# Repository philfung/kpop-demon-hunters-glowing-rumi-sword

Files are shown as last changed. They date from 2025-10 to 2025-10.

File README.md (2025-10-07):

# 🗡️ Rumi's Glowing Sword Prop (KPop Demon Hunters)

This guide provides instructions for creating a lightweight, glowing battery-powered replica of Rumi's sword, scaled for a 5-6 year old to hold comfortably. The sword is designed with a hollow interior to house the LED lighting and internal supports.





WARN: its a bit of work to do this DIY. if you don't enjoy this type of work, they may sell similar items on Etsy.

# ⚙️🔩📄 Bill of Materials

| Item Name | Purpose | Purchase Link |
| :--- | :--- | :--- |
| **3D Print Filament (Translucent Blue/Purple)** | Blade material, allows light pass-through. | https://www.amazon.com/iSANMATE-Filament-Transparent-Printing-Dimensional/dp/B0D4HR3PGB|
| **3D Print Filament (Gold Metal)** | Handle material. | [https://www.amazon.com/dp/B07RBSGZBM](https://www.amazon.com/dp/B07RBSGZBM) |
| **Battery-Powered Thin LED Light Strip** | Internal lighting for the glowing effect. | [https://www.amazon.com/dp/B0C4P9F9Y1](https://www.amazon.com/dp/B0C4P9F9Y1) |
| **Blade Support Rods** | Support the hollow blade| [https://www.amazon.com/dp/B0CN79NZ7Y](https://www.amazon.com/dp/B0CN79NZ7Y) |
| **Handle Support Rod** | Support the handle | https://www.amazon.com/FOCMKEAS-Carbon-6mm-400mm-Airplane/dp/B0DGF28DT8 |
| **Super Glue** | Bond all printed parts, LED strip, and support rods. | [https://www.amazon.com/dp/B0B1H2XD5S](https://www.amazon.com/dp/B0B1H2XD5S) |
| **Clear Tape** | tape LED strip to sword (optional, can use super glue) | https://www.amazon.com/Scotch-Dispenser-Narrow-Engineered-119/dp/B00006IF5G |

*Required tools* 
1. 3D printer
2. needle-nose pliers to remove supports.

---

# 🛠️ Assembly Instructions

1.  **Print Components:** 3D print [all files](3dfiles), using **translucent blue/purple** for parts prefixed with "blue" and **gold metal** for parts prefixed with "gold".
  


2.  **Reinforce Handle:**
   
  A. Glue [handle_1](3dfiles/gold_handle_1.stl) to [handle_2](3dfiles/gold_handle_2.stl)
  
  B. Place the Handle Support Rod through the hole of pieces [handle_2](3dfiles/gold_handle_2.stl), [handle_3](3dfiles/blue_handle_3.stl), [handle_4](3dfiles/gold_handle_4.stl), [handle_5](3dfiles/blue_handle_5.stl), [handle_6](3dfiles/gold_handle_6.stl), [handle_7](3dfiles/gold_handle_7.stl).  Glue pieces [handle_2](3dfiles/gold_handle_2.stl), [handle_3](3dfiles/blue_handle_3.stl), [handle_4](3dfiles/gold_handle_4.stl), [handle_5](3dfiles/blue_handle_5.stl), [handle_6](3dfiles/gold_handle_6.stl), [handle_7](3dfiles/gold_handle_7.stl). together, as well as each piece to the rod.



4.  **Prepare bottom half of the blade**:

  A. Glue [blue_blade_1_bottom](3dfiles/blue_blade_1_bottom.stl), [blue_blade_2_bottom](3dfiles/blue_blade_2_bottom.stl), [blue_blade_3_bottom](3dfiles/blue_blade_3_bottom.stl) together.
  
  B. Insert **two steel support rods** into the hollow interior (one on each side of the center channel) and glue them securely to the plastic walls.



5.  **Attach Handle to Blade:** **Glue** handle to blade, including the handle support rod.



5.  **Route LED Wire:** Pass the **LED strip's power cable** (the end nearest the battery pack/switch) through the dedicated small hole in [blade_1_top](3dfiles/blue_blade_1_top.stl).



6.  **Install Lighting:** Place the **LED strip** along the internal channel of the blade. Secure the strip with **tape and super glue** to prevent shifting and ensure light distribution.  



7.  **Final Closure:** Glue the second half of the blade, i.e [blade_1_top](3dfiles/blue_blade_1_top.stl), [blade_2_top](3dfiles/blue_blade_2_top.stl), [blade_3_top](3dfiles/blue_blade_3_top.stl), together and to the sword to finish the prop.



---

# 🙏 Acknowledgements

The 3d files are modified versions of the [Rumi Sword files from RavenCosplay](https://www.thingiverse.com/thing:7094317), edited to be scaled for a small child and hollowed out for internal electronics and support rods.

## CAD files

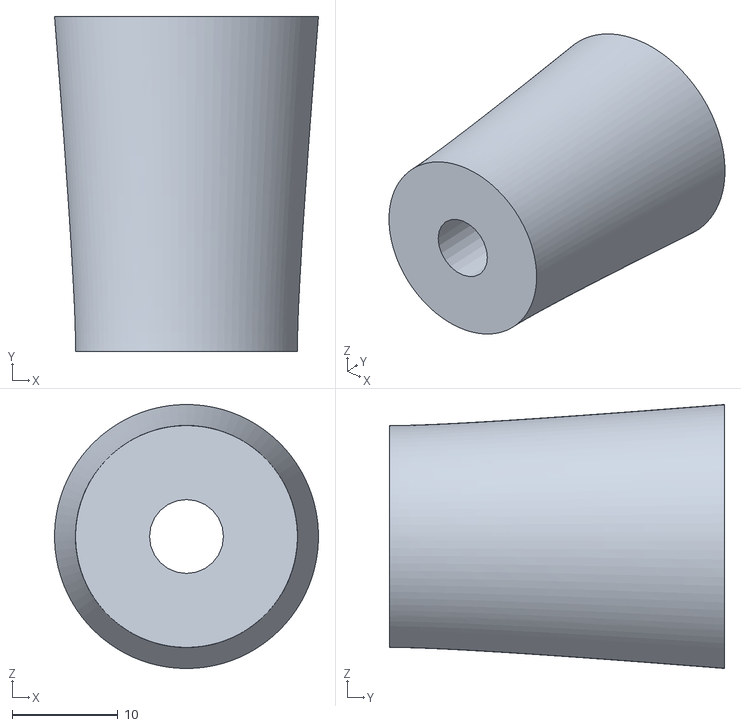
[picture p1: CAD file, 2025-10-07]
3dfiles/blue_handle_3.stl
25.0 x 31.8 x 25.0

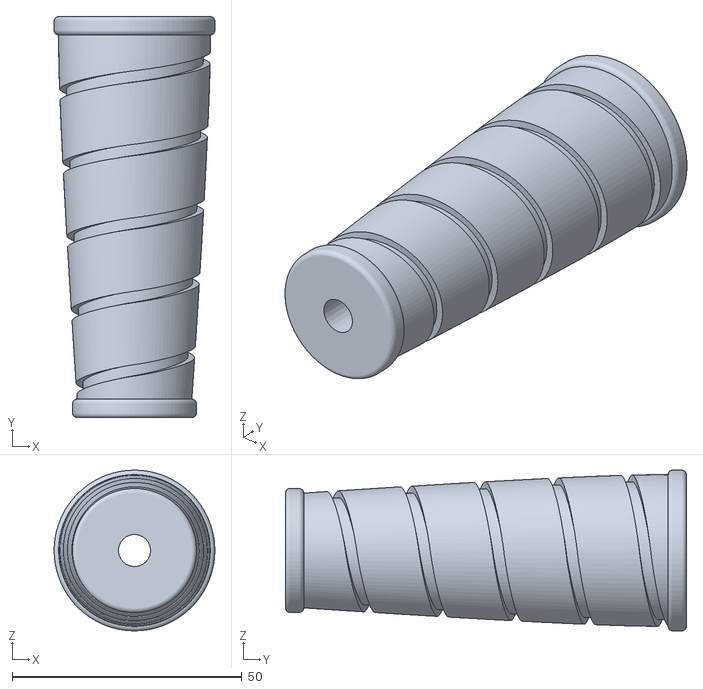
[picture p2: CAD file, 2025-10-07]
3dfiles/gold_handle_4.stl
35.0 x 87.3 x 35.0

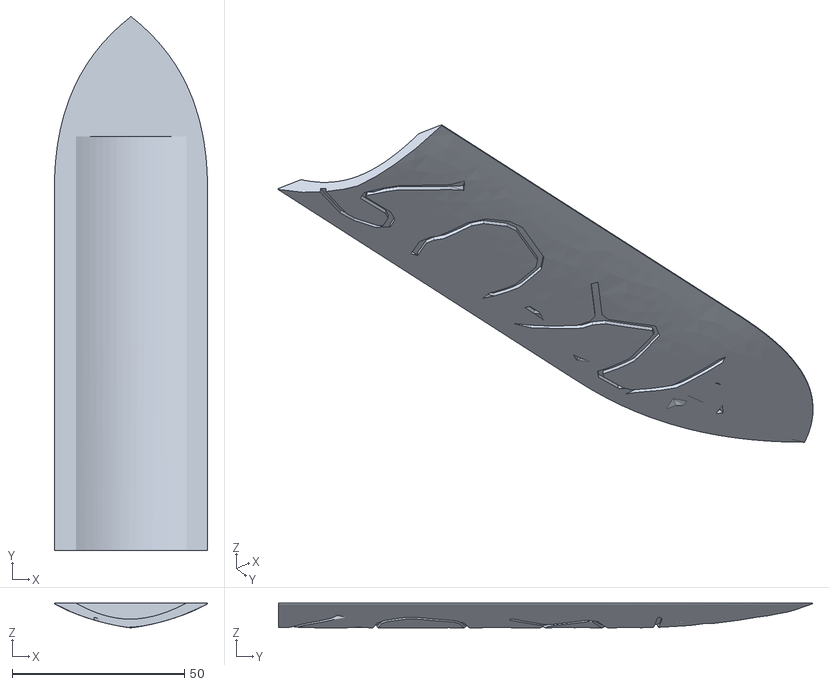
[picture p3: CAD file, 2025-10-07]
3dfiles/blue_blade_3_top.stl
44.5 x 154.9 x 7.21

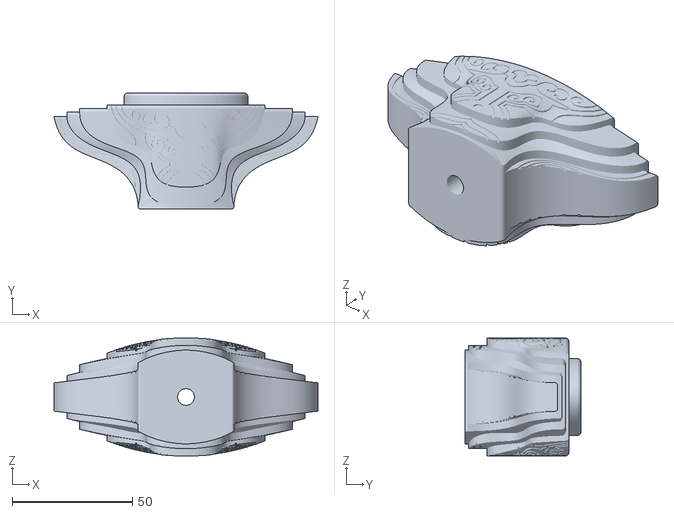
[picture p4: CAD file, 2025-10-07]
3dfiles/gold_handle_7.stl
109.8 x 48.2 x 49.0

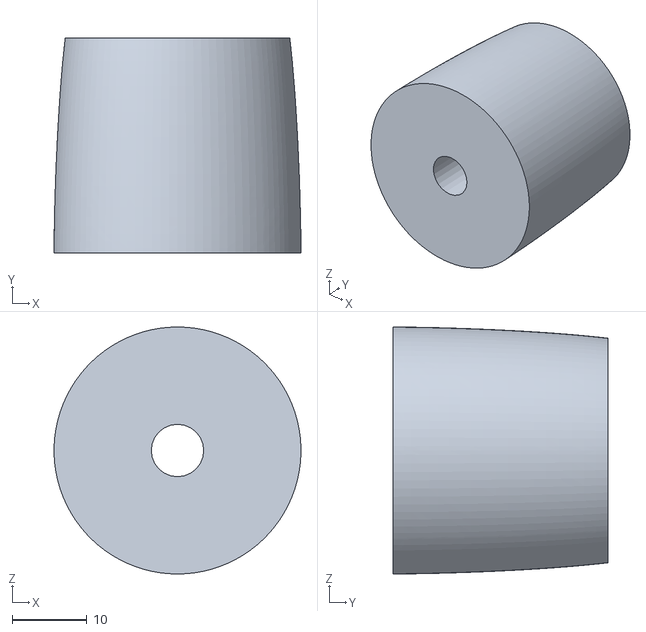
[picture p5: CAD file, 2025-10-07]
3dfiles/blue_handle_5.stl
33.0 x 28.8 x 33.0

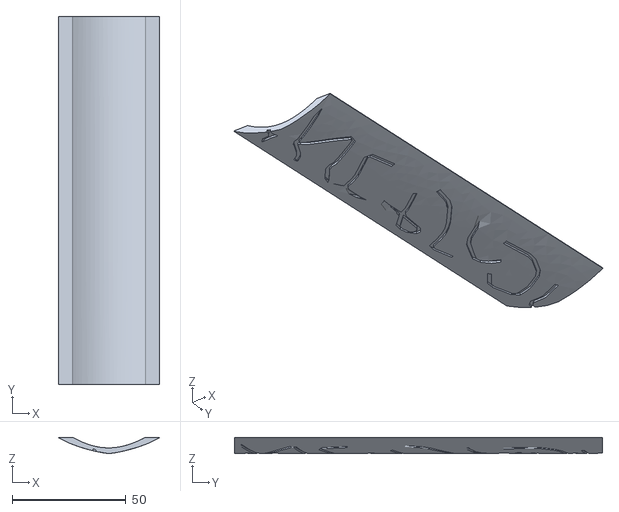
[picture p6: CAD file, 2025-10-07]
3dfiles/blue_blade_2_top.stl
44.5 x 161.6 x 7.21

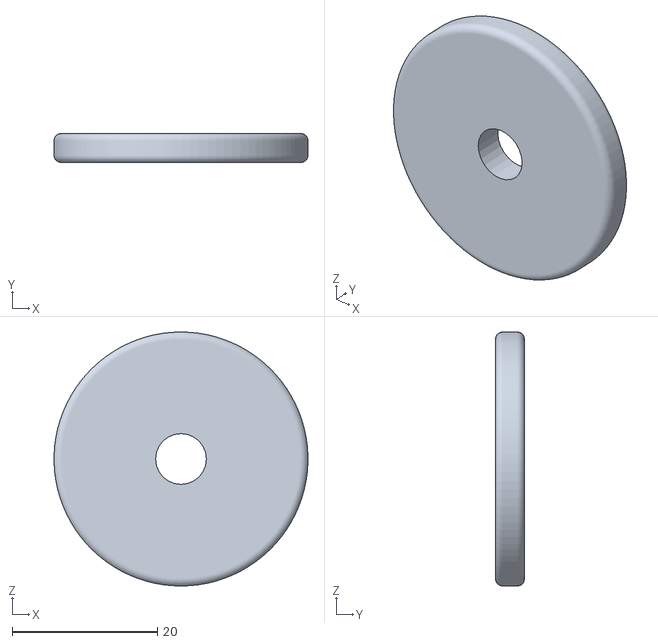
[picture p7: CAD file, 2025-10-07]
3dfiles/gold_handle_6.stl
35.0 x 4.00 x 35.0

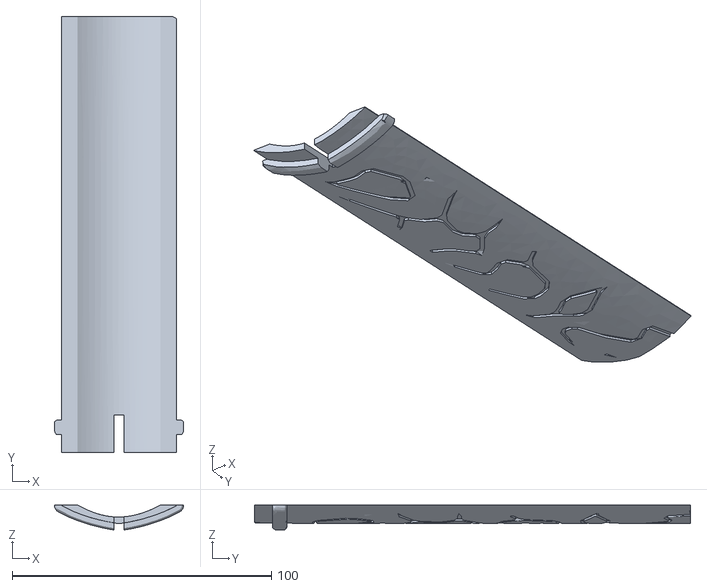
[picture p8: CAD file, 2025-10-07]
3dfiles/blue_blade_1_top.stl
49.9 x 168.2 x 9.64

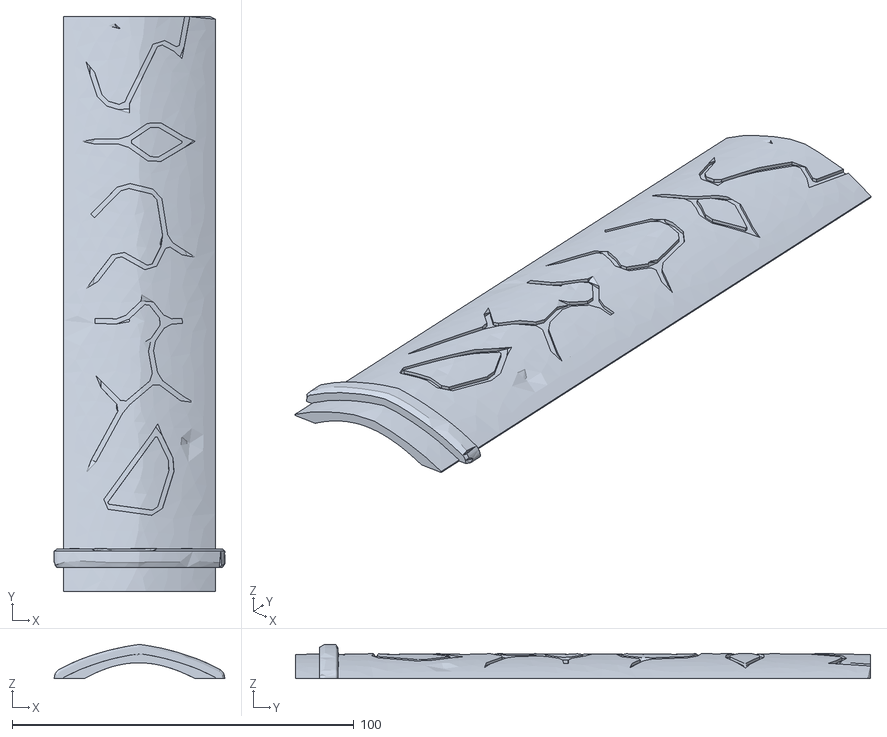
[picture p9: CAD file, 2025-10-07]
3dfiles/blue_blade_1_bottom.stl
49.9 x 168.2 x 10.0

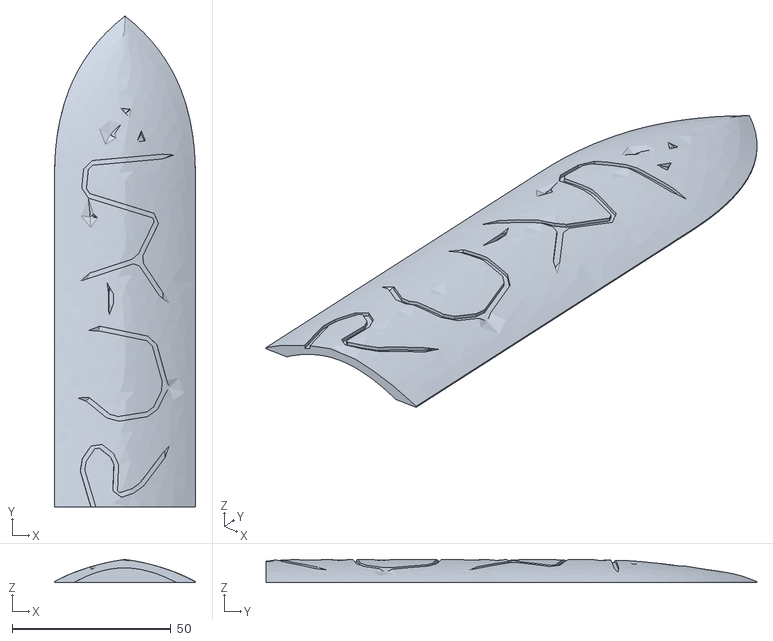
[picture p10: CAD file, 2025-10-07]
3dfiles/blue_blade_3_bottom.stl
44.5 x 154.9 x 7.29

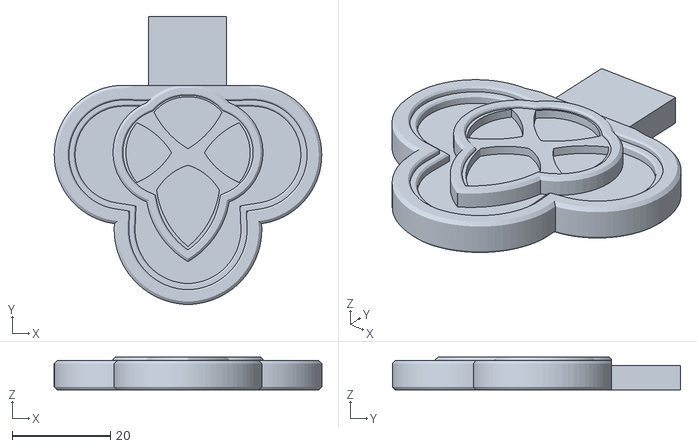
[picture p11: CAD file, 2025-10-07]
3dfiles/gold_handle_1.stl
54.5 x 58.6 x 6.70

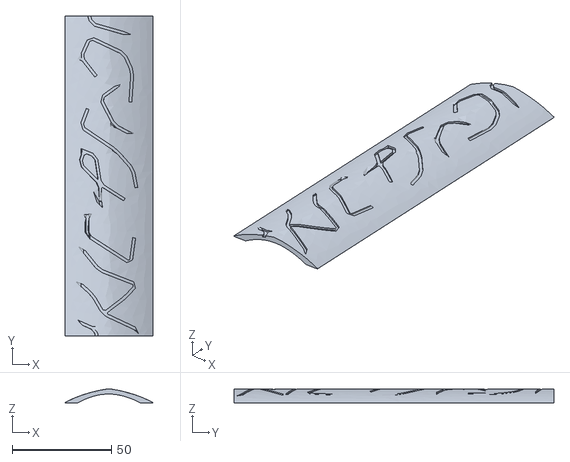
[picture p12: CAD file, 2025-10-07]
3dfiles/blue_blade_2_bottom.stl
44.5 x 161.6 x 7.29

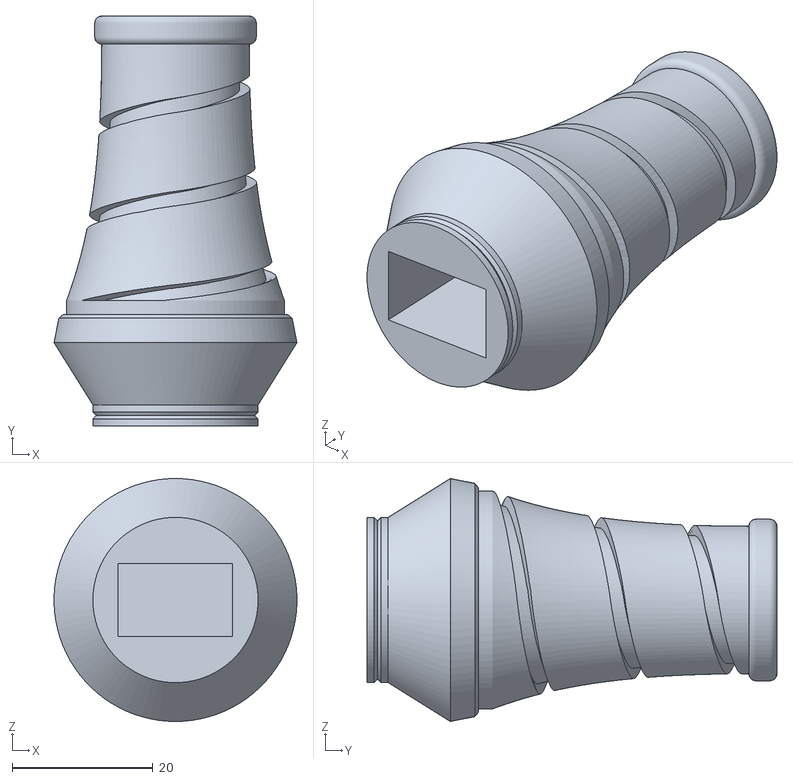
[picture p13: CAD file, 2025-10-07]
3dfiles/gold_handle_2.stl
34.6 x 58.3 x 34.6
